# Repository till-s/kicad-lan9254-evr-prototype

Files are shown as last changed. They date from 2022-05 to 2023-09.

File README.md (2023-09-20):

# EtherCat EVR Prototype

Prototype board of the EtherCat EVR. This is intended to be a
ESC implemented in an FPGA along with a Event Receiver.
Power is supplied to this board via a USB-C (from a compatible port
or power-supply/wal-wart).

At the core of this board is an Artix-7 FPGA which connects to an SFP
from where it receives the timing-system event stream. A 16-bit
parallel interface is connected to a LAN9254 EtherCat controller
device which implements the low-level EtherCat functionality and
drives a twin RJ-45 fast-ethernet connector (EtherCat bus).

## Hardware Features
The board hosts the following hardware:

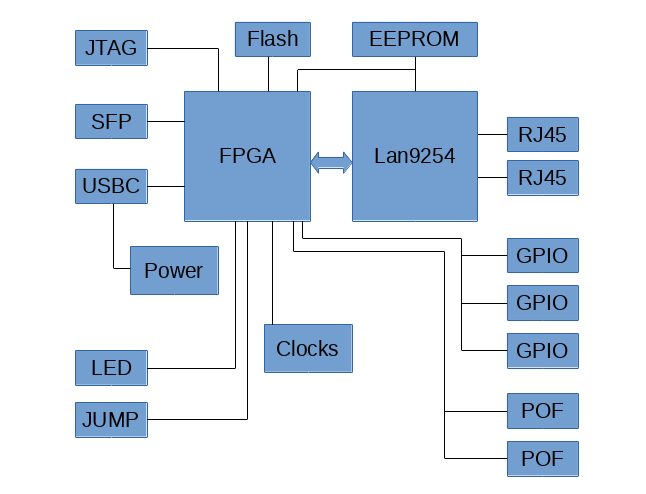
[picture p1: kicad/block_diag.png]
Block Diagram


  - Artix-7 FPGA (xc7a35; note that this was the only device I could
    actually buy in 2022. Was able to secure the last 2 (!) chips from
    Mouser.
  - Configuration flash device.
  - Microchip LAN9254 EtherCAT controller. I also could only secure this
    device via Microchip's sample program (thanks!). At a cost of ~$10
    it is cheaper and faster to use this controller rather than developing
    logic and implementing it in a (bigger!) FPGA device.
  - Twin RJ-45 connector for EtherCAT. They are connected to the LAN9254
    controller.
  - EtherCAT ESC EEPROM. This holds the EtherCAT ESI data and embedded
    ("vendor-specific") non-volatile application parameters. These can
    be modified without having to regenerate a FPGA image/bitstream.
  - SFP cage connected to an Artix-7 MGT.
  - Renesas programmable VersaClock 6 clock generator (one of very few clock
    chip I could get a hand on in 2022). This is used as a refererence clock
    for the EVR MGT as well as a general-purpose clock for FPGA logic.
  - Three LVTTL GPIO ports.
  - Two POF I/O ports (these can drive an LED pulse-id display that can
    e.g., be used to verify camera real-time operation).
  - Several LEDs and jumpers.
  - Power-converters are fed from a single USB-C connector. The power-supply
    can be disabled from an FPGA-pin. This allows the user to implement
    features such as a watchdog or remote-control to self-power cycle the
    system.
  - USB-2 FIFO interface to FPGA (FTDI FT240).
  - JTAG interface connected to FPGA and (optionally) the LAN9254.
    Initial configuration of the FPGA (blank configuration flash) must be
    performed via this interface.

## Component Note

The choice of some components on the board may seem bizarre (e.g., the different types
of voltage-regulators). The explanation is the shortage of devices in 2022; I had
to scramble and in some cases obtain a small amount of samples from vendors and design
with what was available.

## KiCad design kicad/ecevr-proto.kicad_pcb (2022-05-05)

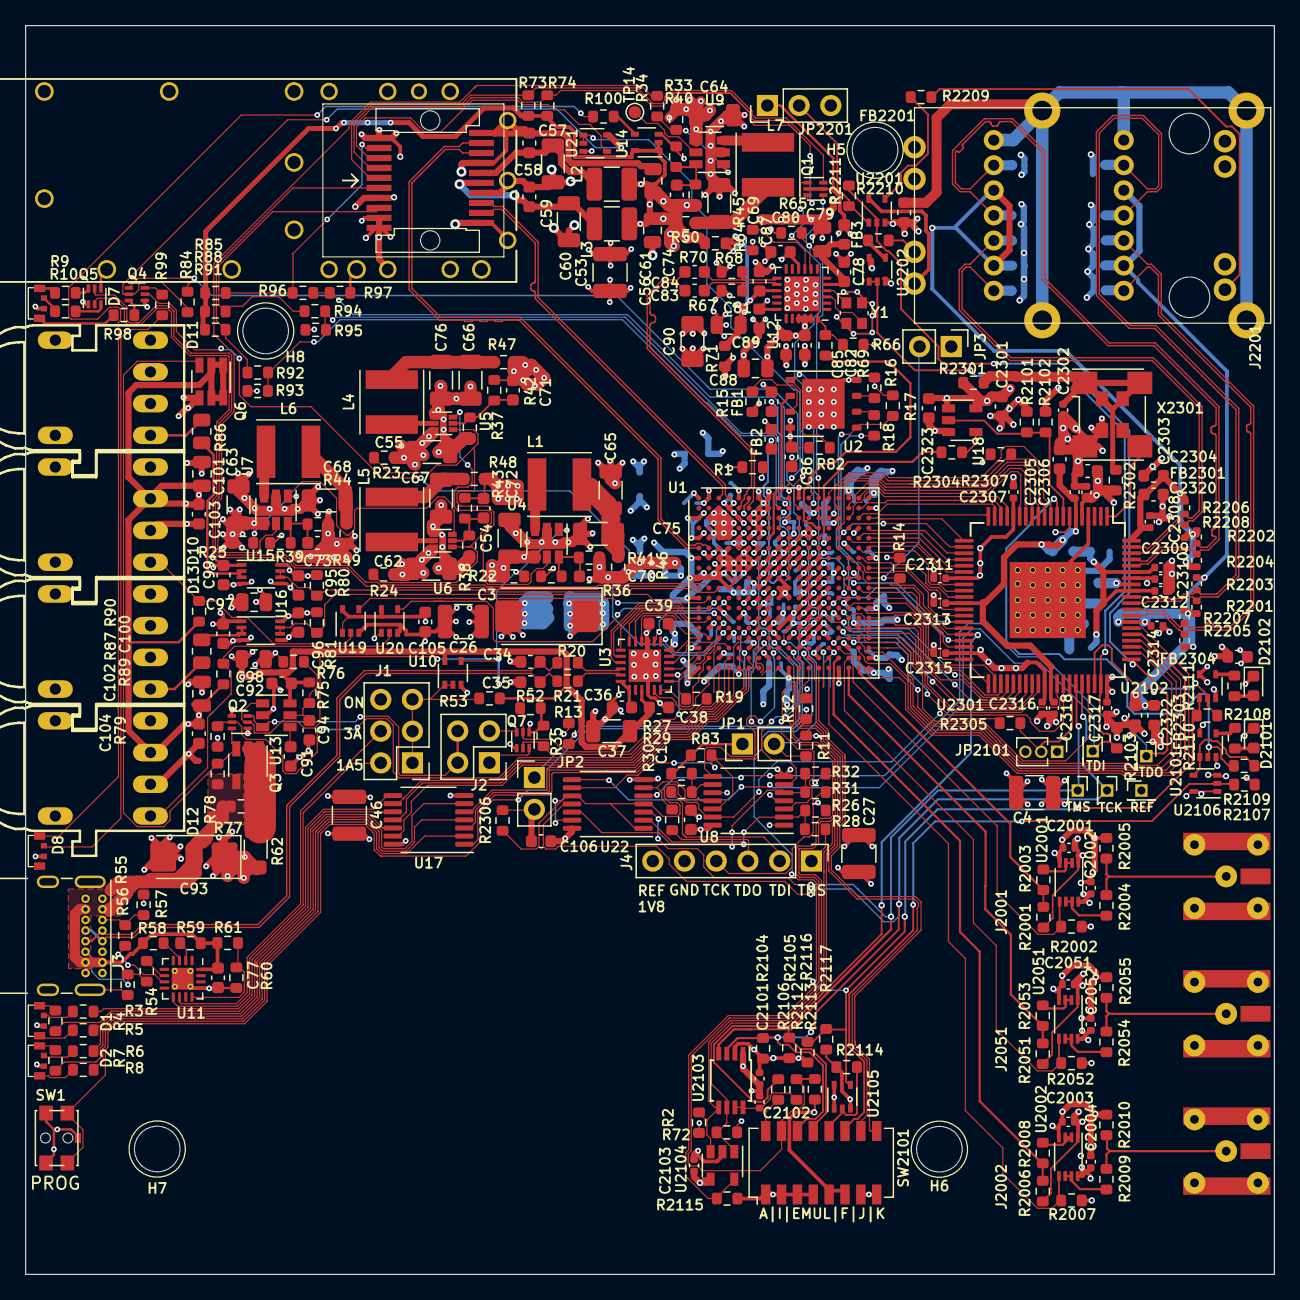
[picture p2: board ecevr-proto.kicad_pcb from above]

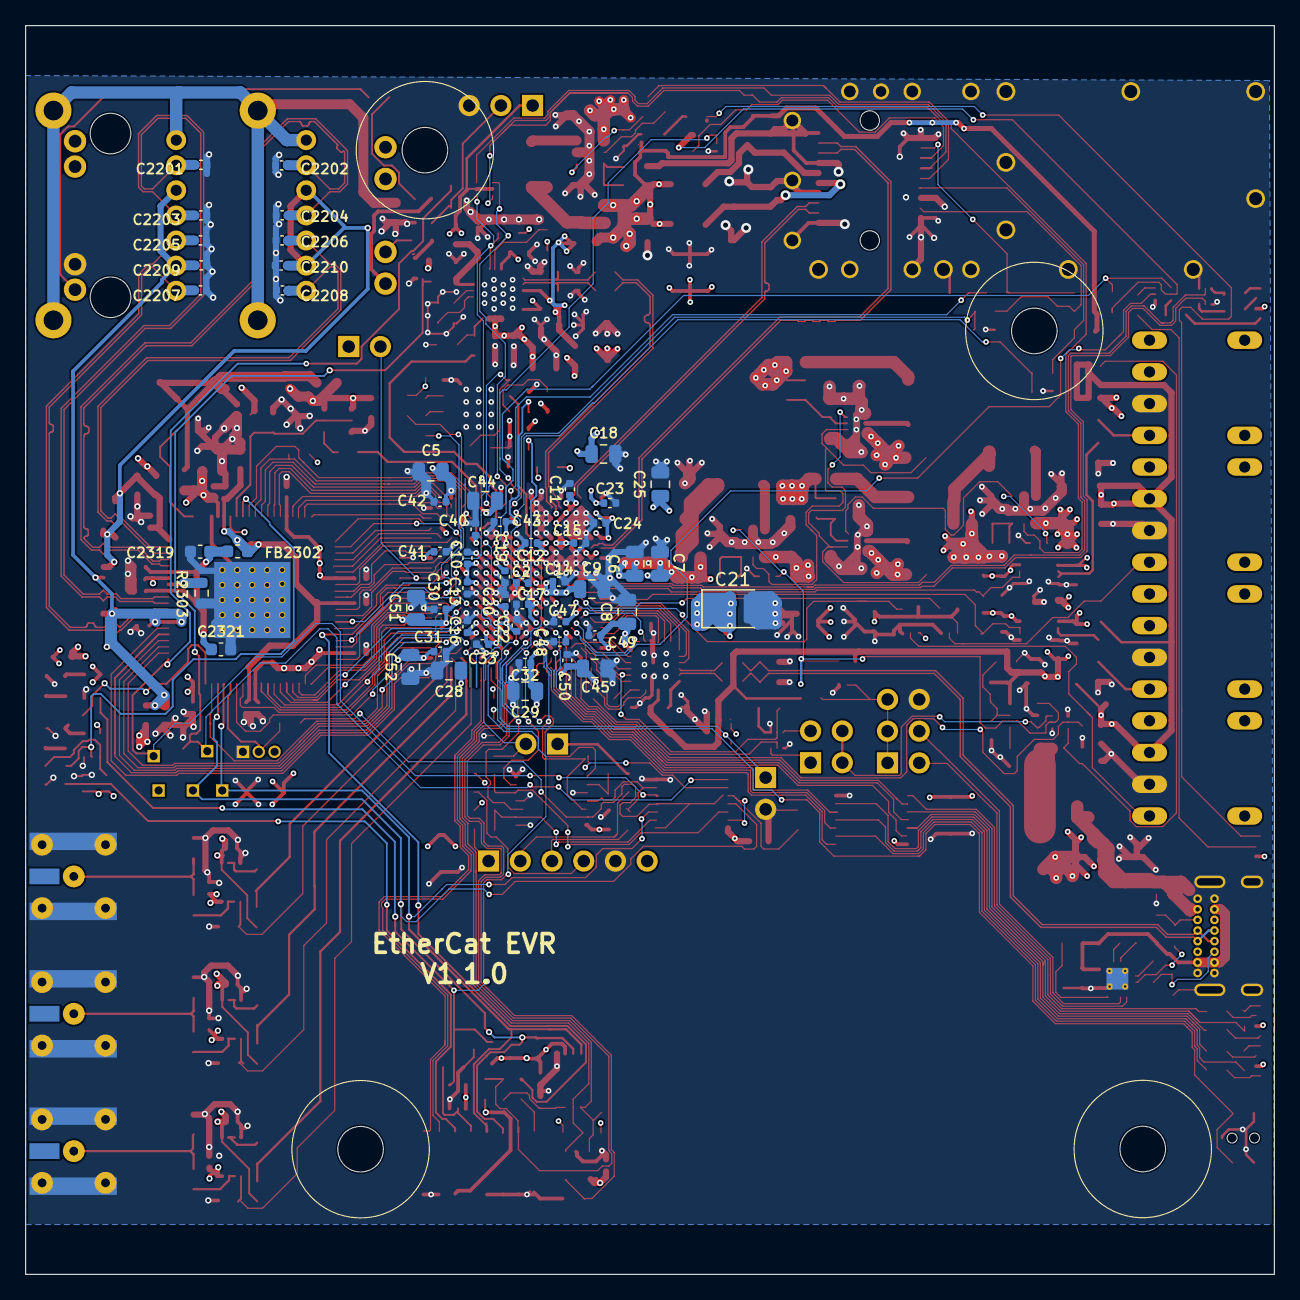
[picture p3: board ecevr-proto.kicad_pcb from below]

Board: 4 copper layers, 100.0 x 100.0 mm, 401 parts (61 on the bottom side), 284 nets.

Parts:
C1, C106: 100nF_603; C_0603_1608Metric
C2, C10, C12, C13, C14, C16, C17, C19, C20, C22, C30, C31, C32, C33, C40, C41, C42, C43, C47, C48, C49, C50: 470n; C_0402_1005Metric
C3: 330u; CP_EIA-7343-30_AVX-N
C4, C26, C27, C46, C53: 47u; C_1210_3225Metric
C5, C6, C7, C8, C9, C18, C25, C28, C29, C44, C45, C51, C52: 4u7; C_0805_2012Metric
C11, C15, C23, C24, C2001, C2002, C2003, C2004, C2051, C2052, C2101, C2103, C2302, C2306, C2307, C2308, C2309, C2310, C2311, C2312, C2313, C2314, C2315, C2316, C2317, C2318: 100n; C_0402_1005Metric
C21: 100u; CP_EIA-3528-15_AVX-H
C34, C35: 47p; C_0603_1608Metric
C36, C38, C39, C77, C78, C80, C81, C82, C83, C84, C85, C86, C87, C91, C92, C2323: 100n; C_0603_1608Metric
C37, C54, C55, C57, C60, C62, C63, C64, C68, C69, C90: 10u; C_1206_3216Metric
C56, C61: 1uF_805; C_0805_2012Metric
C58, C59: 10nF_603; C_0603_1608Metric
C65, C66, C67, C75, C76: 22u; C_1206_3216Metric
C70, C71: 86p; C_0603_1608Metric
C72, C73: 56p; C_0603_1608Metric
C74: 130p; C_0603_1608Metric
C79, C88, C89: 1u; C_0805_2012Metric
C93: 220u; CP_EIA-6032-28_Kemet-C
C94: 1n; C_0603_1608Metric
C95, C96, C99, C100, C103, C104, C105: 100nF; C_0603_1608Metric
C97, C98, C101, C102: 1uF; C_0805_2012Metric
C2102: 100p; C_0402_1005Metric
C2201, C2202, C2203, C2204, C2205, C2206, C2207, C2208, C2209, C2210: 10p; C_0402_1005Metric
C2301, C2303, C2304: 1u_loESR; C_0603_1608Metric
C2305: 470p; C_0402_1005Metric
C2319, C2320, C2321, C2322: 1u; C_0603_1608Metric
D1, D2, D7, D8: LED_BARG; LED_RGB_2504_horiz_barg
D10, D12: HFBR2528; HFBR25XX
D11, D13: HFBR1528; HFBR25XX
D2101, D2102: LED; LED_0603_1608Metric
FB1, FB2, FB2201, FB2301, FB2302, FB2303, FB2304: FB_250; L_0603_1608Metric
FB3: Ferrite_Bead; L_0603_1608Metric
H5, H6, H7, H8: Foot; foot_ff-13
J1: CUR_SEL; PinHeader_2x03_P2.54mm_Vertical
J2: PEN_SEL; PinHeader_2x02_P2.54mm_Vertical
J3: USB_C_Receptacle_USB2.0; USB_C_Receptacle_GCT_USB4085_smaller_holes
J4: JTAG; PinHeader_1x06_P2.54mm_Vertical
J19: SFP; TE_1367073-1
J20: SFP_CAGE; sfp-cage-msa
J2001, J2002, J2051: IO_CONN; LEMO+SMA
J2201: BEL_0845_2G1T_H5; BEL_0845-2G1T-H5
JP1: JTAG_boot; PinHeader_1x02_P2.54mm_Vertical
JP2: INITb; PinHeader_1x02_P2.54mm_Vertical
JP3: PUDC_dis; PinHeader_1x02_P2.54mm_Vertical
JP2101: Jumper_3_Bridged12; PinHeader_1x03_P1.27mm_Vertical
JP2201: 100FDb; PinHeader_1x03_P2.54mm_Vertical
L1, L6, L7: 2u2; L_Taiyo-Yuden_NR-50xx
L2, L3: 1uH; L_1210_3225Metric
L4, L5: 1u; L_Taiyo-Yuden_NR-50xx
Q1, Q2, Q4, Q5, Q7: SSM6N35AFE; SOT-563-adjusted
Q3, Q6: Si3477; TSOT-23-6
R1, R28, R29, R30, R31, R2003, R2008, R2053: 100; R_0603_1608Metric
R2, R64, R65, R72, R2002, R2007, R2052, R2104, R2105, R2111: 3k3; R_0603_1608Metric
R3, R6, R10, R99: 750; R_0603_1608Metric
R4, R7, R9, R100: 2k; R_0603_1608Metric
R5, R8, R98: 230; R_0603_1608Metric
R11, R14, R89, R90, R2101, R2102, R2103, R2106: 1k; R_0603_1608Metric
R12, R13, R84, R85, R88, R91: 4k7; R_0603_1608Metric
R15, R16, R17, R35, R40, R52, R54, R55, R58, R59, R66, R73, R74, R76, R79, R2108, R2115, R2211, R2306, R2307: 10k; R_0603_1608Metric
R18, R67, R68, R77, R2304: 50; R_0603_1608Metric
R19, R34, R46, R47, R48, R49, R50, R70, R71, R2004, R2009, R2054, R2116, R2117, R2301, R2302, R2305: 0; R_0603_1608Metric
R20, R21: 27; R_0603_1608Metric
R22, R23, R24, R25, R26, R27, R32, R33, R53, R78, R80, R81, R82, R83, R2001, R2005, R2006, R2010, R2051, R2055, R2107, R2112, R2113, R2114: 100k; R_0603_1608Metric
R36, R37, R38, R43, R44: 24k; R_0603_1608Metric
R39: 12k; R_0603_1608Metric
R41, R42: 16k; R_0603_1608Metric
R45: 45k3; R_0603_1608Metric
R56, R57, R60, R2109: 5k1; R_0603_1608Metric
R61: 35k7; R_0603_1608Metric
R62: 0.01; R_1206_3216Metric
R69: 33; R_0603_1608Metric
R75: 45.3k; R_0603_1608Metric
R86, R87: 100; R_0805_2012Metric
R92, R93, R94, R95, R96, R97: 47k; R_0603_1608Metric
R2110: 1k5; R_0603_1608Metric
R2201, R2202, R2203, R2204, R2205, R2206, R2207, R2208: 50; R_0402_1005Metric
R2209, R2210: 178; R_0603_1608Metric
R2303: 12.1k; R_0603_1608Metric
SW1: PROG; SW_SPST_PTS810_and_PTS841
SW2101: SW_DIP_x08; SW_DIP_SPSTx08_Slide_Copal_CHS-08A_W5.08mm_P1.27mm_JPin
TP1, TP2, TP3, TP4, TP6, TP7, TP10, TP11, TP12, TP13: Dummy End; endpoint_0.1mm
TP14: TestPoint; TestPoint_Pad_D1.0mm
TP2301: TDO; PinHeader_1x01_P1.27mm_Vertical
TP2302: TDI; PinHeader_1x01_P1.27mm_Vertical
TP2303: TCK; PinHeader_1x01_P1.27mm_Vertical
TP2304: TMS; PinHeader_1x01_P1.27mm_Vertical
TP2305: REF; PinHeader_1x01_P1.27mm_Vertical
U1: XC7A35T-CSG325; Xilinx_CSG325
U2: AT25SL641; WSON-8-1EP_6x5mm_P1.27mm_EP3.4x4mm
U3: FT240XQ; QFN-24-1EP_4x4mm_P0.5mm_EP2.6x2.6mm
U4, U7, U9: TLV62569ADDC; SOT-23-6
U5, U6: TPS62A01A-SOT563; SOT-563
U8: 74ALVC125; TSSOP-14_4.4x5mm_P0.65mm
U10, U14, U21, U2202: 74LVC1G06; SOT-353_SC-70-5
U11: UTC2000; QFN-16-1EP_3x3mm_P0.5mm_EP1.75x1.75mm_ThermalVias
U12: 5P49V6965; QFN-24-1EP_4x4mm_P0.5mm_EP2.8x2.8mm
U13: TPS3808DBV; SOT-23-6
U15, U16, U2001, U2002, U2051: 74LVC2T45DC; VSSOP-8_2.3x2mm_P0.5mm
U17: 74LVC06; TSSOP-14_4.4x5mm_P0.65mm
U18: 74LVC1T126; SOT-23-5
U19, U20, U2101, U2102, U2105, U2106, U2201: 74AHC1T86; SOT-353_SC-70-5
U22: 74AC126; TSSOP-14_4.4x5mm_P0.65mm
U2103: PCA9306; TSSOP-8_3x3mm_P0.65mm
U2104: 24FC16T; SOT-23-5
U2301: lan9254; TQFP-80_12x12mm_P0.5mm_EP6x6mm
X2301: FNETHE025; FNETH_and_ASE-4Pin_3.2x2.5mm
Y1: 25MHz; Crystal_SMD_Abracon_ABM10-4Pin_2.5x2.0mm

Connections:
+1V0: C3.1, C6.1, C7.1, C9.1, C12.1, C14.1, C17.1, C19.1, C20.1, C21.1, C22.1, C70.1, R41.1, R46.1, U1.F7, U1.F9, U1.F11, U1.G8, U1.G10, U1.H7, U1.H9, U1.H11, U1.J8, U1.J12, U1.K7, U1.K11, U1.L8, U1.L12, U1.M7, U1.M11, U1.N8, U1.N10, U1.N12, U1.P9, U1.P11
+1V8: C1.2, C4.1, C5.1, C8.1, C10.1, C13.1, C16.1, C26.1, C27.1, C28.1, C29.1, C30.1, C31.1, C32.1, C33.1, C39.2, C40.1, C41.1, C42.1, C43.1, C44.1, C45.1, C46.1, C47.1, C48.1, C49.1, C50.1, C51.1, C52.1, C53.1, C73.1, C80.2, C81.2, C82.2, C85.2, C86.1, C88.1, C90.1, C95.2, C96.2, C105.2, C106.2, C2001.1, C2003.1, C2051.1, C2101.1, C2103.1, C2301.1, C2307.1, C2311.1, C2315.1, C2316.1, C2317.1, C2323.2, FB2.1, FB3.1, J4.6, JP1.1, JP3.1, JP2101.3, JP2201.1, Q1.2, Q1.5, Q4.5, R2.1, R12.2, R13.2, R15.1, R16.1, R17.1, R26.1, R27.1, R32.1, R44.1, R49.1, R64.2, R65.2, R71.2, R72.1, R80.2, R81.2, R82.1, R83.1, R84.2, R2001.1, R2006.1, R2051.1, R2104.1, R2105.1, R2113.1, R2116.2, R2301.1, R2307.2, SW2101.5, SW2101.6, TP2305.1, U1.A16, U1.B13, U1.C10, U1.D17, U1.E10, U1.E14, U1.G12, U1.G18, U1.H13, U1.H15, U1.K13, U1.L6, U1.L16, U1.M3, U1.M13, U1.P7, U1.P13, U1.P17, U1.R4, U1.R10, U1.R12, U1.R14, U1.T1, U1.T11, U1.U8, U1.U18, U1.V5, U1.V15, U2.8, U3.24, U8.14, U12.10, U12.18, U12.21, U12.22, U12.23, U15.8, U16.8, U17.14, U18.1, U18.5, U19.1, U19.5, U20.1, U20.5, U21.5, U22.14, U2001.1, U2002.1, U2051.1, U2103.2, U2104.4, U2105.1, U2105.5, U2202.5, U2301.16, U2301.27, U2301.39, U2301.50, U2301.60
+3V3: C56.1, C61.1, C74.1, C2002.1, C2004.1, C2052.1, C2304.1, C2306.1, FB2301.1, FB2303.1, FB2304.1, J2201.19, L2.2, L3.2, R45.1, R50.1, R70.2, R73.1, R74.1, R85.2, R88.2, R91.2, R2102.2, R2302.1, U14.1, U14.2, U14.5, U2001.8, U2002.8, U2051.8, U2101.5, U2102.5, U2106.1, U2106.5, U2201.5, U2301.5, U2301.7
+5V: C37.1, C38.2, C54.1, C55.1, C62.1, C63.1, C64.1, C92.1, C93.1, C97.1, C98.1, C99.2, C100.2, D1.2, D2.2, D7.2, D8.2, Q6.4, R22.2, R23.2, R24.2, R25.2, R33.2, R53.1, R62.1, R75.2, U3.15, U4.4, U5.3, U6.3, U7.4, U9.4, U10.5, U13.6, U15.1, U16.1
+5V_SWITCHED: C101.1, C102.1, C103.2, C104.2, D10.3, D12.3, Q6.1, Q6.2, Q6.5, Q6.6, R89.2, R90.2
/CFG_DONE: Q4.4, R84.1, U1.F12
/LAN9254_JTAG_EN: R2305.1, R2306.1, U8.13, U22.1, U22.4, U22.10, U22.13
/SFP Connector/TX_DISABLE: J19.3, U21.4
/USB, JTAG, I2C/USBD_N: R21.2, U3.11
/USB, JTAG, I2C/USBD_P: R20.2, U3.10
/fpga/1V0_MGT: C11.1, C15.1, C18.1, C71.1, R42.1, R47.1, U1.B4, U1.C5, U1.E5, U1.F5
/fpga/1V2_MGT: C23.1, C24.1, C25.1, C72.1, R1.1, R43.1, R48.1, U1.A2, U1.C1, U1.E1, U1.F3, U1.G2
/fpga/fpga_bank0_cfg/AGND: C2.2, FB1.1, U1.J9, U1.K9, U1.K10, U1.L9, U1.L10
/fpga/fpga_bank0_cfg/CCLK: U1.E8, U2.6
/lan9254/EESCL: R2104.2, SW2101.14, TP2303.1, U22.11, U2103.3, U2301.56
/lan9254/EESDA: R2105.2, SW2101.13, TP2304.1, U22.3, U2103.4, U2301.55
/lan9254/ERRLED: R2109.1, U2101.2, U2301.9
/lan9254/LINKACT0: R2211.2, TP2301.1, U22.5, U2201.2, U2301.61
/lan9254/LINKACT1: R2103.1, TP2302.1, U22.8, U2202.1, U2202.2, U2301.59
/lan9254/RUNLED: R2108.1, U2102.2, U2301.58
/lan9254/TESTMODE: JP2101.2, R2305.2, U2301.54
/lan9254/VDD12TX12: C2309.2, C2312.2, C2319.1, C2321.1, FB2302.2, U2301.72, U2301.75
/lan9254/VDD33BIAS: C2310.2, FB2304.2, U2301.74
/lan9254/VDD33TXRX1: C2209.1, C2314.2, C2322.1, FB2303.2, J2201.2, J2201.5, R2201.1, R2203.1, R2205.1, R2207.1, U2301.67
/lan9254/VDD33TXRX2: C2210.1, C2308.2, C2320.1, FB2301.2, J2201.9, J2201.12, R2202.1, R2204.1, R2206.1, R2208.1, U2301.80
/lan9254/VDDCR: C2303.1, C2305.1, C2313.1, C2318.1, FB2302.1, U2301.6, U2301.31, U2301.51
/lan9254/XTAL_MODE: R2101.1, R2102.1, U18.2, U2301.8
/lan9254/rj45_ports/P0_RXD_N: C2201.1, J2201.6, R2201.2, U2301.70
/lan9254/rj45_ports/P0_RXD_P: C2203.1, J2201.4, R2203.2, U2301.71
/lan9254/rj45_ports/P0_TXD_N: C2205.1, J2201.3, R2205.2, U2301.68
/lan9254/rj45_ports/P0_TXD_P: C2207.1, J2201.1, R2207.2, U2301.69
/lan9254/rj45_ports/P1_RXD_N: C2202.1, J2201.13, R2202.2, U2301.77
/lan9254/rj45_ports/P1_RXD_P: C2204.1, J2201.11, R2204.2, U2301.76
/lan9254/rj45_ports/P1_TXD_N: C2206.1, J2201.10, R2206.2, U2301.79
/lan9254/rj45_ports/P1_TXD_P: C2208.1, J2201.8, R2208.2, U2301.78
/mgt_refclk/CLK_OUT_N: C84.2, R68.2, U12.13
/mgt_refclk/CLK_OUT_P: C83.2, R67.1, U12.14
/power/1A5: J1.2, U11.9
/power/3A0: J1.4, U11.10
/power/PWR_EN: Q2.2, R22.1, U4.1, U10.4, U13.1
GND: C1.1, C3.2, C4.2, C5.2, C6.2, C7.2, C8.2, C9.2, C10.2, C11.2, C12.2, C13.2, C14.2, C15.2, C16.2, C17.2, C18.2, C19.2, C20.2, C21.2, C22.2, C23.2, C24.2, C25.2, C26.2, C27.2, C28.2, C29.2, C30.2, C31.2, C32.2, C33.2, C34.1, C35.2, C36.1, C37.2, C38.1, C39.1, C40.2, C41.2, C42.2, C43.2, C44.2, C45.2, C46.2, C47.2, C48.2, C49.2, C50.2, C51.2, C52.2, C53.2, C54.2, C55.2, C56.2, C57.2, C58.2, C59.2, C60.2, C61.2, C62.2, C63.2, C64.2, C65.2, C66.2, C67.2, C68.2, C69.2, C75.2, C76.2, C77.2, C78.1, C79.2, C80.1, C81.1, C82.1, C85.1, C86.2, C87.1, C88.2, C89.2, C90.2, C91.2, C92.2, C93.2, C94.2, C95.1, C96.1, C97.2, C98.2, C99.1, C100.1, C101.2, C102.2, C103.1, C104.1, C105.1, C106.1, C2001.2, C2002.2, C2003.2, C2004.2, C2051.2, C2052.2, C2101.2, C2102.2, C2103.2, C2201.2, C2202.2, C2203.2, C2204.2, C2205.2, C2206.2, C2207.2, C2208.2, C2209.2, C2210.2, C2301.2, C2302.2, C2303.2, C2304.2, C2305.2, C2306.2, C2307.2, C2308.1, C2309.1, C2310.1, C2311.2, C2312.1, C2313.2, C2314.1, C2315.2, C2316.2, C2317.2, C2318.2, C2319.2, C2320.2, C2321.2, C2322.2, C2323.1, D10.2, D11.2, D12.2, D13.2, D2101.1, D2102.1, FB1.2, FB2201.2, J1.6, J3.A1, J3.A12, J3.B1, J3.B12, J3.S1, J4.5, J19.1, J19.7, J19.9, J19.10, J19.11, J19.14, J19.17, J19.20, J20.1, J20.2, J20.3, J20.4, J20.5, J20.6, J20.7, J20.8, J20.9, J20.10, J20.11, J20.12, J20.13, J20.14, J20.15, J20.16, J20.17, J20.18, J20.19, J20.20, J2001.2, J2002.2, J2051.2, J2201.16, JP2.2, JP2101.1, JP2201.3, Q2.1, Q2.4, Q4.1, Q5.1, Q5.4, Q7.1, Q7.4, R11.1, R14.1, R35.2, R36.2, R37.2, R38.2, R39.2, R40.2, R52.2, R56.2, R57.2, R60.2, R66.1, R67.2, R68.1, R76.1, R79.2, R93.1, R95.1, R97.1, R2002.2, R2005.2, R2007.2, R2010.2, R2052.2, R2055.2, R2101.2, R2103.2, R2107.1, R2114.1, R2115.2, R2117.2, R2303.1, R2306.2, SW1.1, SW1.3, SW2101.1, SW2101.2, SW2101.3, SW2101.4, SW2101.7, SW2101.8, U1.A1, U1.A5, U1.A7, U1.A8, U1.A11, U1.A18, U1.B3, U1.B7, U1.B8, U1.B18, U1.C2, U1.C3, U1.C4, U1.C6, U1.C7, U1.C15, U1.D3, U1.D4, U1.D7, U1.D12, U1.E2, U1.E3, U1.E4, U1.E6, U1.E7, U1.E9, U1.E11, U1.E12, U1.F4, U1.F6, U1.F10, U1.F16, U1.G1, U1.G3, U1.G4, U1.G5, U1.G6, U1.G7, U1.G9, U1.G11, U1.G13, U1.H3, U1.H4, U1.H5, U1.H6, U1.H8, U1.H10, U1.H12, U1.J1, U1.J2, U1.J3, U1.J7, U1.J11, U1.J13, U1.J17, U1.K4, U1.K8, U1.K12, U1.K14, U1.L1, U1.L7, U1.L11, U1.L13, U1.M8, U1.M12, U1.M18, U1.N5, U1.N7, U1.N9, U1.N11, U1.N13, U1.N15, U1.P2, U1.P8, U1.P12, U1.R9, U1.R11, U1.T6, U1.T16, U1.U3, U1.U13, U1.V1, U1.V10, U1.V18, U2.4, U2.9, U3.3, U3.16, U3.25, U4.2, U5.1, U6.1, U7.2, U8.1, U8.4, U8.7, U8.10, U9.2, U10.3, U11.13, U11.17, U12.25, U13.2, U14.3, U15.4, U15.5, U16.4, U16.5, U17.7, U18.3, U19.3, U20.3, U21.3, U22.7, U2001.4, U2002.4, U2051.4, U2101.3, U2102.3, U2103.1, U2104.2, U2105.3, U2106.3, U2201.3, U2202.3, U2301.4, U2301.81, X2301.2, Y1.2, Y1.4
IO_25_14: R2115.1, U1.U10, U2104.5
IO_25_34: U1.R6, U17.13
IO_L2N_T0_AD8N_15: R92.1, R93.2, U1.C9
IO_L2N_T0_D03_14: U1.J16, U2301.34
IO_L3N_T0_DQS_34: Q5.2, U1.K1
IO_L3N_T0_DQS_AD1N_15: U1.A9, U21.1, U21.2
IO_L3N_T0_DQS_EMCCLK_14: R2106.1, U1.K18, U2301.36
IO_L3P_T0_DQS_34: Q5.5, U1.K2
IO_L4N_T0_15: Q1.1, R64.1, U1.B11, U12.9
IO_L4N_T0_34: R81.1, U1.L2, U16.6, U16.7
IO_L4N_T0_D05_14: U1.L18, U2301.40
IO_L4P_T0_34: R80.1, U1.K3, U15.6, U15.7
IO_L4P_T0_D04_14: U1.K17, U2301.38
IO_L5N_T0_34: U1.L3, U19.4
IO_L5N_T0_AD9N_15: R96.1, R97.2, U1.A10
IO_L5P_T0_AD9P_15: R94.1, R95.2, U1.B10
IO_L6N_T0_D08_VREF_14: U1.M15, U2301.44
IO_L7N_T1_34: U1.M1, U3.9
IO_L7N_T1_AD2N_15: TP2.1, U1.A12
IO_L7N_T1_D10_14: U1.M17, U2301.41
IO_L7P_T1_34: U1.M2, U3.8
IO_L7P_T1_AD2P_15: TP1.1, U1.B12
IO_L7P_T1_D09_14: U1.M16, U2301.42
IO_L8N_T1_AD10N_15: U1.A14, U2301.10
IO_L8N_T1_D12_14: U1.N14, U2301.46
IO_L8P_T1_AD10P_15: Q1.4, R65.1, U1.A13, U12.8
IO_L8P_T1_D11_14: U1.M14, U2301.37
IO_L9N_T1_DQS_34: U1.P1, U3.5
IO_L9N_T1_DQS_AD3N_15: R2307.1, U1.B15, U2301.11
IO_L9N_T1_DQS_D13_14: U1.N17, U2301.49
IO_L9P_T1_DQS_14: U1.N16, U2301.45
IO_L9P_T1_DQS_34: U1.N1, U3.7
IO_L9P_T1_DQS_AD3P_15: TP3.1, U1.C14
IO_L10N_T1_AD11N_15: U1.A15, U2301.12
IO_L10N_T1_D15_14: U1.P18, U2301.47
IO_L10P_T1_34: U1.M4, U20.4
IO_L10P_T1_D14_14: U1.N18, U2301.43
IO_L11N_T1_SRCC_14: U1.P16, U2301.57
IO_L11N_T1_SRCC_34: U1.N2, U3.6
IO_L11P_T1_SRCC_14: U1.P15, U2301.48
IO_L11P_T1_SRCC_15: R69.1, U1.D13
IO_L11P_T1_SRCC_34: U1.N3, U3.2
IO_L12N_T1_MRCC_14: U1.R15, U2301.53
IO_L12N_T1_MRCC_34: U1.P3, U3.1
IO_L12P_T1_MRCC_15: R2304.2, U1.E13
IO_L12P_T1_MRCC_34: Q4.2, U1.P4
IO_L13N_T2_MRCC_14: R2002.1, U1.T15, U2001.5
IO_L13N_T2_MRCC_15: U1.D15, U2301.13
IO_L13N_T2_MRCC_34: U1.R1, U3.23
IO_L13P_T2_MRCC_14: TP4.1, U1.T14
IO_L13P_T2_MRCC_15: U1.E15, U2301.22
IO_L13P_T2_MRCC_34: U1.R2, U3.4
IO_L14N_T2_SRCC_14: U1.R17, U2301.64
IO_L14N_T2_SRCC_15: U1.D16, U2301.21
IO_L14N_T2_SRCC_34: U1.T2, U3.21
IO_L14P_T2_SRCC_14: U1.R16, U2301.62
IO_L14P_T2_SRCC_15: U1.E16, U2301.26
IO_L14P_T2_SRCC_34: U1.R3, U3.22
IO_L15N_T2_DQS_34: Q7.5, R52.1, U1.U1, U3.20
IO_L15N_T2_DQS_ADV_B_15: U1.A17, U2301.15
IO_L15N_T2_DQS_DOUT_CSO_B_14: U1.T18, U2301.63
IO_L15P_T2_DQS_15: U1.B16, U2301.14
IO_L15P_T2_DQS_34: U1.U2, U3.18
IO_L15P_T2_DQS_RDWR_B_14: U1.R18, U2301.52
IO_L16N_T2_34: U1.V2, U3.17
IO_L16N_T2_A15_D31_14: U1.U17, U2301.66
IO_L16N_T2_A27_15: U1.B17, U2301.18
IO_L16P_T2_34: Q2.5, R79.1, U1.V3
IO_L16P_T2_A28_15: U1.C16, U2301.17
IO_L16P_T2_CSI_B_14: U1.T17, U2301.65
IO_L17N_T2_34: TP10.1, U1.T3
IO_L17N_T2_A13_D29_14: R2052.1, U1.U16, U2051.5
IO_L17N_T2_A25_15: U1.D18, U2301.23
IO_L17P_T2_34: R19.1, U1.T4, U3.19
IO_L17P_T2_A14_D30_14: R2006.2, R2008.1, U1.U15
IO_L17P_T2_A26_15: U1.E17, U2301.24
IO_L18N_T2_34: U1.V4, U17.11
IO_L18N_T2_A11_D27_14: R2001.2, R2003.1, U1.V17
IO_L18N_T2_A23_15: U1.C18, U2301.20
IO_L18P_T2_34: U1.U4, U17.9
IO_L18P_T2_A12_D28_14: R2051.2, R2053.1, U1.V16
IO_L18P_T2_A24_15: U1.C17, U2301.19
IO_L19N_T3_A09_D25_VREF_14: TP6.1, U1.T13
IO_L19N_T3_A21_VREF_15: U1.F18, U2301.28
IO_L19P_T3_34: TP11.1, U1.P6
IO_L19P_T3_A22_15: U1.G17, U2301.30
IO_L20N_T3_34: U1.U5, U17.5
IO_L20N_T3_A07_D23_14: R2007.1, U1.V14, U2002.5
IO_L20N_T3_A19_15: U1.G16, U2301.33
IO_L20P_T3_34: U1.U6, U17.1
IO_L20P_T3_A08_D24_14: TP7.1, U1.U14
IO_L21N_T3_DQS_34: TP12.1, U1.T5
IO_L21N_T3_DQS_A06_D22_14: SW2101.9, U1.V13
IO_L21P_T3_DQS_14: R72.2, U1.V12, U2103.6, U2104.1
IO_L22N_T3_A04_D20_14: SW2101.10, U1.U12
IO_L22P_T3_34: TP13.1, U1.R7
IO_L22P_T3_A05_D21_14: R2108.2, R2116.1, R2117.1, U1.T12, U2102.1, U2105.4
IO_L23N_T3_34: U1.V6, U17.3
IO_L23N_T3_A02_D18_14: R2112.1, R2113.2, SW2101.15, U1.V11
IO_L23N_T3_FWE_B_15: U1.H18, U2301.32
IO_L23P_T3_A03_D19_14: R2.2, U1.U11, U2103.5, U2104.3
IO_L23P_T3_FOE_B_15: U1.H17, U2301.35
IO_L24N_T3_RS0_15: U1.E18, U2301.25
IO_L24P_T3_RS1_15: U1.F17, U2301.29
MGT_REFCLK_N: C84.1, U1.B5
MGT_REFCLK_P: C83.1, U1.B6
MGT_RX1_N: J19.12, U1.A3
MGT_RX1_P: J19.13, U1.A4
MGT_TX1_N: J19.19, U1.F1
MGT_TX1_P: J19.18, U1.F2
unnamed: C2.1, FB2.2, U1.J10
unnamed: C36.2, U3.12, U3.13
unnamed: C57.1, C58.1, J19.16, L2.1
unnamed: C59.1, C60.1, J19.15, L3.1
unnamed: C65.1, C75.1, L1.2, R46.2
unnamed: C66.1, C76.1, L4.2, R47.2
unnamed: C67.1, L5.2, R48.2
unnamed: C68.1, L6.2, R49.2
unnamed: C69.1, L7.2, R50.2
unnamed: C70.2, R36.1, R41.2, U4.6
unnamed: C71.2, R37.1, R42.2, U5.5
unnamed: C72.2, R38.1, R43.2, U6.5
unnamed: C73.2, R39.1, R44.2, U7.6
unnamed: C74.2, R40.1, R45.2, U9.6
unnamed: C78.2, C79.1, FB3.2, U12.5
unnamed: C87.2, C89.1, R70.1, R71.1, U12.15
unnamed: C91.1, U13.4
unnamed: C94.1, R75.1, R76.2, U13.5
unnamed: C2102.1, R2112.2, U2103.7, U2103.8
unnamed: C2302.1, R2301.2, R2302.2, X2301.1, X2301.4
unnamed: D1.1, R5.2
unnamed: D1.3, R3.2
unnamed: D1.4, R4.2
unnamed: D2.1, R8.2
unnamed: D2.3, R6.2
unnamed: D2.4, R7.2
unnamed: D7.1, R98.1
unnamed: D7.3, R10.1
unnamed: D7.4, R9.1
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

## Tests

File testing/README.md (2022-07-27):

# Testing

Various tests can be performed with JTAG (see 'jtag_test.py').
Also, the EEPROM can be written via JTAG.

## Problems
 - could *not* get chained lan9254 JTAG to work. Even connecting
   the header directly to the test points (removing R2305)
   did *not* work. On the developement board, OTOH direct connection
   to the test points did work.
   Verified TESTMODE solder joint several times. The other pins
   work since LINKACT0/1,EEPSCL,EEPSDA all work.
   Wonder if the chip is defective (but everything else seems to
   work).

 - usb-FIFO did not work (chip defective?) even though the chip
   was detected on USB and the soldering looked perfect.
   => Removed the chip (maybe a bad idea?). Replacing seems difficult
   and maybe not worth it.
   RXE/TXF flag initial values seemed wrong; the FIFO could not
   be accessed from the FPGA side. Voltage levels were fine.

 - JTAG/pullup strangeness: while many pins with the internal
   pull-ups would work as expected (pull up when pin switched
   to input mode) the FIFO pins (and some unconnected ones in the
   same bank) would not be pulled up:
      set as output to '0'
      set as input
      readback still '0'

## Component Tests
 - LEDS        => JTAG
 - GPIO        => JTAG
 - POF         => JTAG
 - FIFO        => JTAG (did not work)
 - EEPROM      => JTAG
 - ETHERCAT    => (set to DIGIO in EEPROM, test)
 - JUMPERS     => JTAG
 - PLL         => JTAG
 - power-cycle => JTAG
 - FPGA/LAN
   interconn   => JTAG / ECAT (since JTAG did not work,
                  verified at least the DIGIO connections
                  by setting in FPGA from JTAG and reading
                  back via ECAT). All other connections can
                  also be verified (with special EEPROM images)
 - LAN RST     => JTAG
 - ECAT LEDS   => ECAT (ERRLED w/o EEPROM requires active high ERRLED)
 - SFP         => JTAG (EEPROM), IBERT test app (GTP, control-signals)
 - SPI FLASH   => JTAG (detection)

## EcEvrIBERTest Application:
use IBERT (MUST USE EXAMPLE DESIGN; adding just the IP lacks all the constraints)

    1. create dummy app, add ibert IP (refclk = 125mhz, sysclk = extern, 125mhz)
    2. menu from IP source, create example design
    3. modify 

        a) remove sysclk buffer, connect refclk via BUFG to ibert core
        b) SFP connections (including TXDISb := '1')
             TXDISb                 -> jumper 8 (with pullup)
             LOS/PRESENTb/TXFAULT   -> LED
             pllClk, lanClk, refclk -> counters -> LED

    5. program PLL via JTAG
    6. run app and test

        - GTP (external loopback, no polarity reversal required) 
        - SFP readback
        - jumper8/TXDISb (this toggles RXLOS)
        - clocks

       verify:

               1) led(0/1/2) blinking (pllClk, lan9254Clk, refClk)
               2) jumper 8 off
               3) w/o SFP led(7/8/9) all on
               4) with SPF led(7/8/9) go all off 
               5) jumper8 toggles RED led7 (when RED, TX is disabled)
               6) enable TX and run BERT

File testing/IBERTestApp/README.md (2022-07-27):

Recreate vivado project:

  1. chdir into `vivado/` subdirectory (*important*)
  2. start vivado
  3. source ../EcEvrIberTest.tcl

Any modifications must be propagated back into the tcl script;
nothing under `vivado/` is preserved in git.

*Note*: before starting this test application (i.e., loading its bit-file)
the PLL clock must be programmed (which can be done via JTAG using the 
jtag_test.py software). *Without clock the application does not work*.
Set the clock frequency to 125MHz.

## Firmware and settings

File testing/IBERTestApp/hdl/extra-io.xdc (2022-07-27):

## SFP TX En (not TxDis)
set_property PACKAGE_PIN D13      [get_ports {pllClk}]
set_property IOSTANDARD  LVCMOS18 [get_ports {pllClk}]

create_clock -name pllClk -period 40 [get_ports {pllClk}]
set_clock_groups -group [get_clocks pllClk] -asynchronous

set_property PACKAGE_PIN E13      [get_ports {lan9254Clk}]
set_property IOSTANDARD  LVCMOS18 [get_ports {lan9254Clk}]

create_clock -name lan9254Clk -period 40 [get_ports {lan9254Clk}]
set_clock_groups -group [get_clocks lan9254Clk] -asynchronous

set_property PACKAGE_PIN A9       [get_ports {txEn}]
set_property IOSTANDARD  LVCMOS18 [get_ports {txEn}]

set_property PACKAGE_PIN C9       [get_ports {presentb}]
set_property IOSTANDARD  LVCMOS18 [get_ports {presentb}]

set_property PACKAGE_PIN B10      [get_ports {rxLOS}]
set_property IOSTANDARD  LVCMOS18 [get_ports {rxLOS}]

set_property PACKAGE_PIN A10      [get_ports {txFault}]
set_property IOSTANDARD  LVCMOS18 [get_ports {txFault}]

set_property PACKAGE_PIN V13      [get_ports {jumper8}]
set_property IOSTANDARD  LVCMOS18 [get_ports {jumper8}]

set_property PACKAGE_PIN K2       [get_ports {ledR[2]}]
set_property IOSTANDARD  LVCMOS18 [get_ports {ledR[2]}]

set_property PACKAGE_PIN K1       [get_ports {ledG[2]}]
set_property IOSTANDARD  LVCMOS18 [get_ports {ledG[2]}]

set_property PACKAGE_PIN P4       [get_ports {ledB[2]}]
set_property IOSTANDARD  LVCMOS18 [get_ports {ledB[2]}]

set_property PACKAGE_PIN U5       [get_ports {ledR[1]}]
set_property IOSTANDARD  LVCMOS18 [get_ports {ledR[1]}]

set_property PACKAGE_PIN V6       [get_ports {ledG[1]}]
set_property IOSTANDARD  LVCMOS18 [get_ports {ledG[1]}]

set_property PACKAGE_PIN U6       [get_ports {ledB[1]}]
set_property IOSTANDARD  LVCMOS18 [get_ports {ledB[1]}]

set_property PACKAGE_PIN U4       [get_ports {ledR[0]}]
set_property IOSTANDARD  LVCMOS18 [get_ports {ledR[0]}]

set_property PACKAGE_PIN V4       [get_ports {ledG[0]}]
set_property IOSTANDARD  LVCMOS18 [get_ports {ledG[0]}]

set_property PACKAGE_PIN R6       [get_ports {ledB[0]}]
set_property IOSTANDARD  LVCMOS18 [get_ports {ledB[0]}]

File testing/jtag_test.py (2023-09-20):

import urjtag
import os
from   time import sleep
import subprocess
import sys
from   JtagDevUtils import *

def ecGetReg(off, w=32):
  r = subprocess.run(["ethercat", "reg_read", "-tuint{:d}".format(w), "{:d}".format(off)], stdout=subprocess.PIPE)
  return int(r.stdout.split()[0], 0)

def ecSetReg(off, val, w=32):
  r = subprocess.run(["ethercat", "reg_write", "-tuint{:d}".format(w), "{:d}".format(off), "{:d}".format(val)], stdout=subprocess.PIPE)


def ecGetDigInp():
  return ecGetReg(0x1000)

def ecGetDigOut():
  return ecGetReg(0x0f00)

def ecSetDigOut(v):
  ecSetReg(0x0f00, v)

def ecGetLatch(idx):
  lrise = [0x9b0, 0x9c0]
  lfall = [0x9b8, 0x9c8]
  return ecGetReg( lfall[idx], w=64 )

def ecDisableWatchdog():
  ecSetReg(0x420, 0, w=16)
  v = ecGetReg(0x440, w=16)
  if (v & 1) == 0:
    raise RuntimeError("Unable to disable Process Data Watchdog")

def ecEnableWatchdog():
  ecSetReg(0x420, 1000, w=16)

class Chn(JtagTap):

  PLL_CLK_PIN = 'IO_D13'
  LAN_CLK_PIN = 'IO_E13'

  LAN_IO_PINS = [
    'IO_A14',
    'IO_B15',
    'IO_A15',
    'IO_D15',
    'IO_B16',
    'IO_A17',
    'IO_C16',
    'IO_B17',
    'IO_C17',
    'IO_C18',
    'IO_D16',
    'IO_E15',
    'IO_D18',
    'IO_E17',
    'IO_E18',
    'IO_E16',
    'IO_F18',
    'IO_F17',
    'IO_G17',
    'IO_H18',
    'IO_G16',
    'IO_J16',
    'IO_H17',
    'IO_K18',
    'IO_M14',
    'IO_K17',
    'IO_L18',
    'IO_M17',
    'IO_M16',
    'IO_N18',
    'IO_M15',
    'IO_N16',
    'IO_N14',
    'IO_P18',
    'IO_P15',
    'IO_N17',
    'IO_R18',
    'IO_R15',
    'IO_P16',
    'IO_R16',
    'IO_T18',
    'IO_R17',
    'IO_T17',
    'IO_U17'
  ]

  SPIFLASH_CLK_IDX  = 0
  SPIFLASH_SI_IDX   = 1
  SPIFLASH_SO_IDX   = 2
  SPIFLASH_CSb_IDX  = 3

  SPIFLASH_IO_PINS = [
    'CCLK_E8',
    'IO_K16',
    'IO_L17',
    'IO_L15'
  ]
  
  # LATCH/SYNC mapping depends on EEPROM (reg 0x151)
  LAN_LAT_IDXS     = [0,  38]
  LAN_SYN_IDXS     = [29, 11]
  LAN_RST_IDX      = 1
  LAN_SOF_IDX      = 4
  LAN_EOF_IDX      = 5
  LAN_WD_STATE_IDX = 10
  LAN_WD_TRIG_IDX  = 34
  LAN_OUTVALID_IDX = 40
  LAN_LATCH_IN_IDX = 15
  LAN_OE_EXT_IDX   = 19

  LAN_DIGIO_IDXS = [
    35,
    36,
    37,
    39,
    18,
    17,
    16,
    9,
    8,
    27,
    23,
    20,
    21,
    22,
    24,
    25,
    2,
    3,
    6,
    7,
    12,
    13,
    14,
    26,
    28,
    30,
    31,
    32,
    33,
    41,
    42,
    43
  ]

  LAN_HBI_AD_IDXS = [
    10,
     5,
     4,
    34,
    39,
    40,
    35,
    36,
    37,
    15,
    18,
    17,
    16,
     9,
     8,
    27
  ]

  LAN_HBI_BE0_IDX   = 20
  LAN_HBI_BE1_IDX   = 21
  LAN_HBI_RD_IDX    = 25
  LAN_HBI_WR_IDX    = 24
  LAN_HBI_CS_IDX    = 22
  LAN_HBI_WA_IDX    = 0
  LAN_HBI_ALELO_IDX = 19

  LED_PINS = [
    'IO_K2',
    'IO_K1',
    'IO_P4',
    'IO_U4',
    'IO_V4',
    'IO_R6',
    'IO_U5',
    'IO_V6',
    'IO_U6',
   ]

  DONE_PIN = 'DONE_F12'

  POFO_PINS = [
    'IO_K3',
    'IO_L2'
  ];

  POFI_PINS = [
    'IO_L3',
    'IO_M4'
  ];

  GPIO_DAT_PINS = [
    'IO_V17',
    'IO_V16',
    'IO_U15',
  ];

  GPIO_DIR_PINS = [
    'IO_T15',
    'IO_U16',
    'IO_V14',
  ];

  POWER_PIN = 'IO_V3'

  INITb_PIN = 'INIT_B_T10'

  FIFO_PINS = {
    "WR"  : "IO_M1",
    "RDb" : "IO_M2",
    "SIWU": "IO_N1",
    "DAT" : [
            "IO_T2",
            "IO_P3",
            "IO_R1",
            "IO_N2",
            "IO_R3",
            "IO_R2",
            "IO_P1",
            "IO_N3"
    ],
    "CBUS5": "IO_U1",
    "CBUS6": "IO_T4",
    "RXE"  : "IO_U2",
    "TXF"  : "IO_V2"
  }

  I2C_SCL_PINS = [
    'IO_V12',
    'IO_B11'
  ]

  I2C_SDA_PINS = [
    'IO_U11',
    'IO_A13'
  ]

  I2C_RD  = True
  I2C_WR  = False
  I2C_NAK = True 

  I2C_ADDR_CLK = 0x6a

  JUMPER8_PIN    = 'IO_V13'
  JUMPER7_PIN    = 'IO_U12'
  I2C_ISOLb_PIN  = 'IO_V11'

  # programmed device for
  #  CBUS5: TIMESTAMP
  #  CBUS7: SLEEP#
  
  def __init__(self):
    super().__init__( path= "./bsdl/" )
    self.led_    = JtagLED (
                             self,
                             self.LED_PINS,
                             self.DONE_PIN
                           )
    self.gpio_   = JtagGPIO(
                             self,
                             dat_pins = self.GPIO_DAT_PINS,
                             dir_pins = self.GPIO_DIR_PINS
                           )
    self.i2c_    = JtagI2C (
                             self,
                             scl_pins = self.I2C_SCL_PINS,
                             sda_pins = self.I2C_SDA_PINS
                           )
    self.flash_  = JtagSPIFlash(
                             self,
                             clk_pin  = self.SPIFLASH_IO_PINS[self.SPIFLASH_CLK_IDX],
                             mosi_pin = self.SPIFLASH_IO_PINS[self.SPIFLASH_SI_IDX ],
                             miso_pin = self.SPIFLASH_IO_PINS[self.SPIFLASH_SO_IDX ],
                             csb_pin  = self.SPIFLASH_IO_PINS[self.SPIFLASH_CSb_IDX]
                           )

  def fifoInit(self):
    self.fifoSetDat()
    self.urc.set_signal( self.FIFO_PINS["WR"],  0 )
    self.urc.set_signal( self.FIFO_PINS["RDb"], 1 )
    self.urc.shift_dr()

  def checkLeds(self):
    return self.led_.test()

  def checkPOF(self):
    print("Checking POF Outputs -- should be 5V initially, please verify")
    failed = []
    for i in range(len(self.POFO_PINS)):
      print("Prepare measuring voltage at POF {:d} output -- ready [press key]".format(i))
      getyN('')
      self.led_.blinkLo( self.POFO_PINS[i], 1.0 )
      print("Did you see it?")
      if ( not getyN() ):
        failed.append( self.POFO_PINS[i] )
    print("Checking POF Inputs")
    for i in range(len(self.POFI_PINS)):
      if 0 != self.urc_.get_signal(self.POFI_PINS[i]):
        print("POF {:d} input (inverted) initially one -- FAILED".format(i))
        failed.append( self.POFI_PINS[i] )
      else:
        print("Please pull POF {:d} input low -- press key when ready".format(i))
        getyN('')
        self.urc_.shift_dr()
        if 1 != self.urc_.get_signal(self.POFI_PINS[i]):
          print("POF {:d} input (inverted) not one -- FAILED".format(i))
          failed.append( self.POFI_PINS[i] )
    return failed

  def checkGPIO(self):
    return self.gpio_.test()

  def checkPowerCycle(self):
    failed = []
    print("Watch for power-cycle -- ready [key press] ?")
    getyN('')
    self.urc_.set_signal( self.POWER_PIN, 1 )
    self.urc_.shift_dr()
    print("Did you see the power cycle?")
    stat = getyN()
    self.extest()
    if not stat:
      failed.append( self.POWER_PIN )
    return failed

  def fifoSetDat(self, d = None):
    if d is None:
      for s in self.FIFO_PINS["DAT"]:
        self.urc_.set_signal(s)
    else:
      for s in self.FIFO_PINS["DAT"]:
        v = d & 1
        d = d >> 1
        self.urc_.set_signal(s, v)
    self.urc_.shift_dr()

  def fifoGetSig(self, sig):
    return self.urc_.get_signal(self.FIFO_PINS[sig])
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

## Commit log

2021-06-22 gitified original (V1) cpu-carrier-test
    [b2b_conn.sch, cpu-carrier-test.kicad_pcb, cpu-carrier-test.sch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]
2021-06-22 re-routed i2c from mio12/13 -> mio10/11
    Fixed bug; mio12/13 is used internally on the SOM.
    [b2b_conn.sch, peripherals_1.sch]
2021-06-22 re-routed i2c from mio12/13 -> mio10/11 on PCB
    [cpu-carrier-test.kicad_pcb]
2021-06-23 hooked up SD-card; use smaller reset button
    [cpu-carrier-test.kicad_pcb, cpu-carrier-test.sch, peripherals_1.sch]
2021-06-24 prepare for merge script
    [b2b_conn.sch, cpu-carrier-test.sch, peripherals_1.sch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]
2021-06-24 merged power-test sub-PCB
    [cpu-carrier-test.kicad_pcb]
2021-06-24 final merge of power module; passes DRC
    [cpu-carrier-test.kicad_pcb, cpu-carrier-test.sch]
2021-06-28 integrated power/uart sub-board and fixed design rule violatons
    (new violations due to jlcpcb's 0.5mm hole distance)
    [cpu-carrier-test.kicad_pcb, cpu-carrier-test.sch]
2021-06-28 rotated SDIO to face board front
    this allows the power module to be either positioned at its
    original location or -- alternatively, next to the SDIO card
    [cpu-carrier-test.kicad_pcb, peripherals_1.sch]
2021-06-30 added PWR_FLAGs
    [cpu-carrier-test.kicad_pcb, cpu-carrier-test.sch]
2021-07-01 updated power-and-uart (README.md was added)
2021-07-01 changed design rules to jlcpcb 4-layer setup; started reworking diff-pairs
    [cpu-carrier-test.kicad_pcb]
2021-07-01 added gnd and 3V3 layers; redrew board edge and placed power module
    The power module is still unconnected
    [cpu-carrier-test.kicad_pcb]
2021-07-06 don't remember changes :-(
    [cpu-carrier-test.kicad_pcb, cpu-carrier-test.sch]
2021-07-06 added lan9254 module to schematic, reannotated
    [b2b_conn.sch, cpu-carrier-test.sch, peripherals_1.sch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]
2021-07-06 updated power-and-uart submodule (# of sheets has changed)
2021-07-06 merged lan9254 module
    [cpu-carrier-test.kicad_pcb]
2021-07-06 connected lan9254 power to board power
    [cpu-carrier-test.kicad_pcb, cpu-carrier-test.sch]
2021-07-06 connected lan9254 i2c to baseboard SDA0/SDC0
    [cpu-carrier-test.kicad_pcb, cpu-carrier-test.sch]
2021-07-06 b2b_conn.sch: removed redundant local labels (globals already present)
    [b2b_conn.sch]
2021-07-06 converted local- to global labels for B34/B34 B2B pins
    [b2b_conn.sch, cpu-carrier-test.kicad_pcb, cpu-carrier-test.sch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]
2021-07-07 cont. work; all connections done now
    [b2b_conn.sch, cpu-carrier-test.kicad_pcb, cpu-carrier-test.sch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]
2021-07-07 added more component values/part numbers
    [cpu-carrier-test.kicad_pcb, cpu-carrier-test.sch, peripherals_1.sch]
2021-07-08 re-routed usbA (proper diff-pair); added mounting holes
    [cpu-carrier-test.kicad_pcb, cpu-carrier-test.sch, peripherals_1.sch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]
2021-07-09 use rj45/Gige + USB combo connector; hooked up LEDs
    no more GND window under GigE diff-pairs on power-plane
    [cpu-carrier-test.kicad_pcb, peripherals_1.sch, unused.sch]
2021-07-09 power-and-uart: changed inductor to TDK part (availability issues)
2021-07-20 Several changes; converging to prototype version 1.0.0
    Added header for connecting external power-supply (in case
    chips are not available)
    [cpu-carrier-test.kicad_pcb, peripherals_1.sch, sfp-conn.sch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]
2021-07-20 updated gerber options according to jlcbcb instructions
    [cpu-carrier-test.kicad_pcb]
2022-01-26 renamed project files (cpu-carrier-test -> ecevr-proto)
    [ecevr-proto.kicad_pcb, ecevr-proto.sch]
2022-02-02 WIP: (save)
    [dummy.sch, ecevr-proto.kicad_pcb, ecevr-proto.sch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]
2022-02-10 WIP: point before we change to OSH/relaxed process
    [dummy.sch, ecevr-proto.kicad_pcb, ecevr-proto.sch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]
2022-02-10 PCB: reverted design rules to JLCPCB process; starting point before relaxing!
    [ecevr-proto.kicad_pcb]
2022-02-10 re-routed with more relaxed specs (that eurocircuits can also meet)
    No chance with OSH, however...
    Going to place stuff on the board now...
    [ecevr-proto.kicad_pcb, ecevr-proto.sch, no_conn.sch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]
2022-04-28 further work...
    [ecevr-proto.kicad_pcb, ecevr-proto.sch, fpga.sch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]
2022-04-28 pcb: increased board width to 100mmx100mm
    In case we ever use an extruded Al box.
    [ecevr-proto.kicad_pcb]
2022-05-02 PCB: updated USBC-connector footprint, rearranged REF silkscreen text
    UCBC annular rings increased in size (for EuroCircuits)
    [ecevr-proto.kicad_pcb]
2022-05-02 added 3rd GPIO
    [ecevr-proto.kicad_pcb, ecevr-proto.sch, fpga.sch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]
2022-05-05 Added pull-up resistor to lan9254 #RST line
    [ecevr-proto.kicad_pcb]
2022-05-05 updated cap footprint
    [ecevr-proto.kicad_pcb, fpga_power.sch, leds.sch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]
2022-05-31 removed obsolete 'power-and-uart' submodule
2022-07-12 power.sch: changed R79 from 10k to 1k
    10k was not enough to overcome fpga-internal pullup (while device
    unconfigured) and would result in power-cycle.
    [power.sch]
2022-07-27 mgt_refclk.sch: reduced R66 to 1k5 (see README.errata)
    [mgt_refclk.sch]
2022-07-27 moved schematics etc. into kicad/ subdir
    [b2b_conn.sch, ecevr-proto.kicad_pcb, ecevr-proto.sch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]
2022-07-27 added various helper scripts
    scripts to extract info from kicad and/or package files etc.
2022-08-12 jtag_test.py: added more spi flash operations
2023-09-20 jtag_test.py: must store JtagTap not URC in JtagGeneric device 'jtg_'
2023-09-20 jtag_test.py: FIX - SPI flash had MISO/MOSI pins swapped.
    [jtag_test.py]
